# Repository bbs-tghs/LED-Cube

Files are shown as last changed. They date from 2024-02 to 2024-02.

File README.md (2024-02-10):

# LED-Cube
Eine schöne Idee, die sich als wesentlich kniffliger zeigte also zunächst vermutet.
Zunächst haben wir es mit dem ebenfalls hier beschriebenen Übungssystem versucht. Der frei fliegende Aufbau hat aber so viele Probleme verursacht, dass wir eine einzige Platine entwirfen haben, die alle erforderlichen Komponenten enthält. Das sind im Wesentlichen:
- Der Controller
- Die High-Side-Treiber
- Der Multiplexer

Diese Platine hat dann problemlos funktoniert.

So sieht das Ganze dann fertig aus. Eine Acrylglashaube schützt vor Staub. (Ein schöneres Bild brauchen wir aber noch)

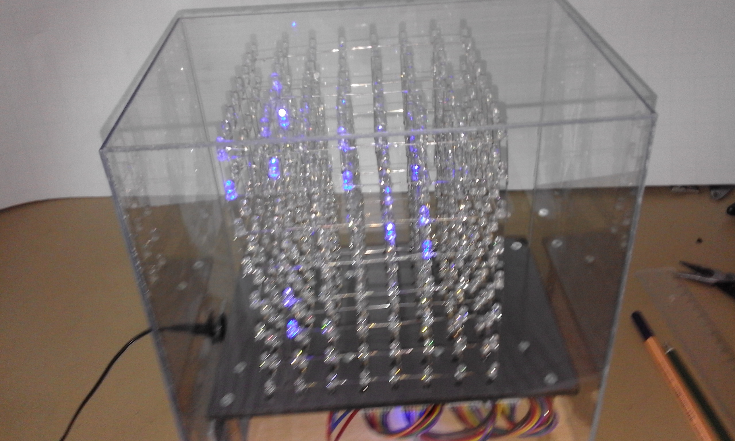
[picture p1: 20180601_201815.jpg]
LED-Cube


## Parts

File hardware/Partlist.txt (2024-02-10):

Partlist

Exported from LEDCube_Par.sch at 02.12.2017 18:35:41

EAGLE Version 5.9.0 Copyright (c) 1988-2010 CadSoft

Part     Value          Device          Package         Library          Sheet

C1       22p            C-EU050-025X075 C050-025X075    bbstghs          1
C2       22p            C-EU050-025X075 C050-025X075    bbstghs          1
C3       100n           C-EU050-025X075 C050-025X075    bbstghs          1
C4       100n           C-EU050-025X075 C050-025X075    bbstghs          1
C5       4u7            CPOL-EUE2-5     E2-5            bbstghs          1
C6       4u7            CPOL-EUE2-5     E2-5            bbstghs          1
C7       100n           C-EU050-030X075 C050-030X075    bbstghs          1
C8       100n           C-EU050-030X075 C050-030X075    bbstghs          1
C9       100n           C-EU050-030X075 C050-030X075    bbstghs          1
C10      100n           C-EU050-030X075 C050-030X075    bbstghs          1
C11      100n           C-EU050-030X075 C050-030X075    bbstghs          1
C12      100n           C-EU050-030X075 C050-030X075    bbstghs          1
C13      100n           C-EU050-030X075 C050-030X075    bbstghs          1
C14      100n           C-EU050-030X075 C050-030X075    bbstghs          1
C15      470p           C-EU050-025X075 C050-025X075    bbstghs          1
C16      470p           C-EU050-025X075 C050-025X075    bbstghs          1
C17      470p           C-EU050-025X075 C050-025X075    bbstghs          1
C18      470p           C-EU050-025X075 C050-025X075    bbstghs          1
C19      470p           C-EU050-025X075 C050-025X075    bbstghs          1
C20      470p           C-EU050-025X075 C050-025X075    bbstghs          1
C21      470p           C-EU050-025X075 C050-025X075    bbstghs          1
C22      470p           C-EU050-025X075 C050-025X075    bbstghs          1
C23      100n           C-EU050-025X075 C050-025X075    bbstghs          1
C25      47µ/25V        CPOL-EUE2-5     E2-5            bbstghs          1
C26      330n           C-EU050-030X075 C050-030X075    bbstghs          1
C27      100n           C-EU050-030X075 C050-030X075    bbstghs          1
C28      10n            C-EU050-030X075 C050-030X075    bbstghs          1
C29      100n           C-EU050-030X075 C050-030X075    bbstghs          1
C30      USB_SHIELED    USB_SHIELED     USB-MB-H-SHIELD con-usb          1
D1       SB320          SB320           DO201-15        bbstghs          1
IC1      UDN2803        ULN2803A        DIL18           uln-udn          1
IC2      UDN2803        ULN2803A        DIL18           uln-udn          1
IC3      UDN2803        ULN2803A        DIL18           uln-udn          1
IC4      UDN2803        ULN2803A        DIL18           uln-udn          1
IC5      UDN2803        ULN2803A        DIL18           uln-udn          1
IC6      UDN2803        ULN2803A        DIL18           uln-udn          1
IC7      UDN2803        ULN2803A        DIL18           uln-udn          1
IC8      UDN2803        ULN2803A        DIL18           uln-udn          1
IC9      74AC573N       74AC573N        DIL20           74xx-eu          1
IC10     74AC573N       74AC573N        DIL20           74xx-eu          1
IC11     74AC573N       74AC573N        DIL20           74xx-eu          1
IC12     74AC573N       74AC573N        DIL20           74xx-eu          1
IC13     74AC573N       74AC573N        DIL20           74xx-eu          1
IC14     74AC573N       74AC573N        DIL20           74xx-eu          1
IC15     74AC573N       74AC573N        DIL20           74xx-eu          1
IC16     74AC573N       74AC573N        DIL20           74xx-eu          1
IC17     MEGA32-P       MEGA32-P        DIL40           atmel            1
IC18                    ULN2803A        DIL18           uln-udn          1
JP1                     JP1E            JP1             bbstghs          1
JP2                     JP1E            JP1             bbstghs          1
LED1                    LED3MM          LED3MM          bbstghs          1
LED2                    LED3MM          LED3MM          bbstghs          1
LED3                    LED3MM          LED3MM          bbstghs          1
LED4                    LED3MM          LED3MM          bbstghs          1
LSP1     LSP10          LSP10           LSP10           solpad           1
LSP2     LSP10          LSP10           LSP10           solpad           1
LSP3     LSP10          LSP10           LSP10           solpad           1
LSP4     LSP11          LSP11           LSP11           solpad           1
Q1       16MHz          CRYSTALHC49U-V  HC49U-V         bbstghs          1
Q2       BD140          BD140           TO126AV         transistor-power 1
Q3       BD140          BD140           TO126AV         transistor-power 1
Q4       BD140          BD140           TO126AV         transistor-power 1
Q5       BD140          BD140           TO126AV         transistor-power 1
Q6       BD140          BD140           TO126AV         transistor-power 1
Q7       BD140          BD140           TO126AV         transistor-power 1
Q8       BD140          BD140           TO126AV         transistor-power 1
Q9       BD140          BD140           TO126AV         transistor-power 1
R1       100R           R-EU_0204/2V    0204V           bbstghs          1
R2       100R           R-EU_0204/2V    0204V           bbstghs          1
R3       100R           R-EU_0204/2V    0204V           bbstghs          1
R4       100R           R-EU_0204/2V    0204V           bbstghs          1
R5       100R           R-EU_0204/2V    0204V           bbstghs          1
R6       100R           R-EU_0204/2V    0204V           bbstghs          1
R7       100R           R-EU_0204/2V    0204V           bbstghs          1
R8       100R           R-EU_0204/2V    0204V           bbstghs          1
R9       100R           R-EU_0204/2V    0204V           bbstghs          1
R10      100R           R-EU_0204/2V    0204V           bbstghs          1
R11      100R           R-EU_0204/2V    0204V           bbstghs          1
R12      100R           R-EU_0204/2V    0204V           bbstghs          1
R13      100R           R-EU_0204/2V    0204V           bbstghs          1
R14      100R           R-EU_0204/2V    0204V           bbstghs          1
R15      100R           R-EU_0204/2V    0204V           bbstghs          1
R16      100R           R-EU_0204/2V    0204V           bbstghs          1
R17      100R           R-EU_0204/2V    0204V           bbstghs          1
R18      100R           R-EU_0204/2V    0204V           bbstghs          1
R19      100R           R-EU_0204/2V    0204V           bbstghs          1
R20      100R           R-EU_0204/2V    0204V           bbstghs          1
R21      100R           R-EU_0204/2V    0204V           bbstghs          1
R22      100R           R-EU_0204/2V    0204V           bbstghs          1
R23      100R           R-EU_0204/2V    0204V           bbstghs          1
R24      100R           R-EU_0204/2V    0204V           bbstghs          1
R25      100R           R-EU_0204/2V    0204V           bbstghs          1
R26      100R           R-EU_0204/2V    0204V           bbstghs          1
R27      100R           R-EU_0204/2V    0204V           bbstghs          1
R28      100R           R-EU_0204/2V    0204V           bbstghs          1
R29      100R           R-EU_0204/2V    0204V           bbstghs          1
R30      100R           R-EU_0204/2V    0204V           bbstghs          1
R31      100R           R-EU_0204/2V    0204V           bbstghs          1
R32      100R           R-EU_0204/2V    0204V           bbstghs          1
R33      100R           R-EU_0204/2V    0204V           bbstghs          1
R34      100R           R-EU_0204/2V    0204V           bbstghs          1
R35      100R           R-EU_0204/2V    0204V           bbstghs          1
R36      100R           R-EU_0204/2V    0204V           bbstghs          1
R37      100R           R-EU_0204/2V    0204V           bbstghs          1
R38      100R           R-EU_0204/2V    0204V           bbstghs          1
R39      100R           R-EU_0204/2V    0204V           bbstghs          1
R40      100R           R-EU_0204/2V    0204V           bbstghs          1
R41      100R           R-EU_0204/2V    0204V           bbstghs          1
R42      100R           R-EU_0204/2V    0204V           bbstghs          1
R43      100R           R-EU_0204/2V    0204V           bbstghs          1
R44      100R           R-EU_0204/2V    0204V           bbstghs          1
R45      100R           R-EU_0204/2V    0204V           bbstghs          1
R46      100R           R-EU_0204/2V    0204V           bbstghs          1
R47      100R           R-EU_0204/2V    0204V           bbstghs          1
R48      100R           R-EU_0204/2V    0204V           bbstghs          1
R49      100R           R-EU_0204/2V    0204V           bbstghs          1
R50      100R           R-EU_0204/2V    0204V           bbstghs          1
R51      100R           R-EU_0204/2V    0204V           bbstghs          1
R52      100R           R-EU_0204/2V    0204V           bbstghs          1
R53      100R           R-EU_0204/2V    0204V           bbstghs          1
R54      100R           R-EU_0204/2V    0204V           bbstghs          1
R55      100R           R-EU_0204/2V    0204V           bbstghs          1
R56      100R           R-EU_0204/2V    0204V           bbstghs          1
R57      100R           R-EU_0204/2V    0204V           bbstghs          1
R58      100R           R-EU_0204/2V    0204V           bbstghs          1
R59      100R           R-EU_0204/2V    0204V           bbstghs          1
R60      100R           R-EU_0204/2V    0204V           bbstghs          1
R61      100R           R-EU_0204/2V    0204V           bbstghs          1
R62      100R           R-EU_0204/2V    0204V           bbstghs          1
R63      100R           R-EU_0204/2V    0204V           bbstghs          1
R64      100R           R-EU_0204/2V    0204V           bbstghs          1
R65      10k            R-EU_0207/10    0207/10         bbstghs          1
R66      100k           R-EU_0207/10    0207/10         bbstghs          1
R67      10R            R-EU_0207/10    0207/10         bbstghs          1
R68      100R           R-EU_0207/2V    0207/2V         bbstghs          1
R69      100R           R-EU_0207/2V    0207/2V         bbstghs          1
R70      100R           R-EU_0207/2V    0207/2V         bbstghs          1
R71      100R           R-EU_0207/2V    0207/2V         bbstghs          1
R72      100R           R-EU_0207/2V    0207/2V         bbstghs          1
R73      100R           R-EU_0207/2V    0207/2V         bbstghs          1
R74      100R           R-EU_0207/2V    0207/2V         bbstghs          1
R75      100R           R-EU_0207/2V    0207/2V         bbstghs          1
R76      10M            R-EU_0207/10    0207/10         bbstghs          1
R77      1k8            R-EU_0207/2V    0207/2V         bbstghs          1
R78      1k8            R-EU_0207/2V    0207/2V         bbstghs          1
R79      1k8            R-EU_0207/2V    0207/2V         bbstghs          1
R80      1k8            R-EU_0207/2V    0207/2V         bbstghs          1
R81      10k            R-EU_0207/2V    0207/2V         bbstghs          1
R82      10k            R-EU_0207/2V    0207/2V         bbstghs          1
R83      4k7            R-EU_0207/10    0207/10         bbstghs          1
R84      2k2            R-EU_0207/2V    0207/2V         bbstghs          1
R86      4k7            R-EU_0207/10    0207/10         bbstghs          1
R87      2k2            R-EU_0207/2V    0207/2V         bbstghs          1
R89      4k7            R-EU_0207/10    0207/10         bbstghs          1
R90      2k2            R-EU_0207/2V    0207/2V         bbstghs          1
R92      4k7            R-EU_0207/10    0207/10         bbstghs          1
R93      2k2            R-EU_0207/2V    0207/2V         bbstghs          1
R95      4k7            R-EU_0207/10    0207/10         bbstghs          1
R96      2k2            R-EU_0207/2V    0207/2V         bbstghs          1
R98      4k7            R-EU_0207/10    0207/10         bbstghs          1
R99      2k2            R-EU_0207/2V    0207/2V         bbstghs          1
R101     4k7            R-EU_0207/10    0207/10         bbstghs          1
R102     2k2            R-EU_0207/2V    0207/2V         bbstghs          1
R104     4k7            R-EU_0207/10    0207/10         bbstghs          1
R105     2k2            R-EU_0207/2V    0207/2V         bbstghs          1
R107     10k            R-EU_0207/10    0207/10         bbstghs          1
S1                      10-XX           B3F-10XX        switch-omron     1
SV1                     MA08-1          MA08-1          con-lstb         1
SV2                     MA08-1          MA08-1          con-lstb         1
SV3                     MA08-1          MA08-1          con-lstb         1
SV4                     MA08-1          MA08-1          con-lstb         1
SV5                     MA08-1          MA08-1          con-lstb         1
SV6                     MA08-1          MA08-1          con-lstb         1
SV7                     MA08-1          MA08-1          con-lstb         1
SV8                     MA08-1          MA08-1          con-lstb         1
SV9                     MA08-1          MA08-1          con-lstb         1
SV10                    ML6             ML6             bbstghs          1
SV11                    MA08-1          MA08-1          con-lstb         1
U2       MCP2221        MCP2221         DIL14           bbstghs          1
V1       74238N         74238N          DIL16           74ttl-din        1
X1                      AK500/2         AK500/2         bbstghs          1
X2                      AK500/2         AK500/2         bbstghs          1
X3                      AK500/10        AK500/10        con-ptr500       1

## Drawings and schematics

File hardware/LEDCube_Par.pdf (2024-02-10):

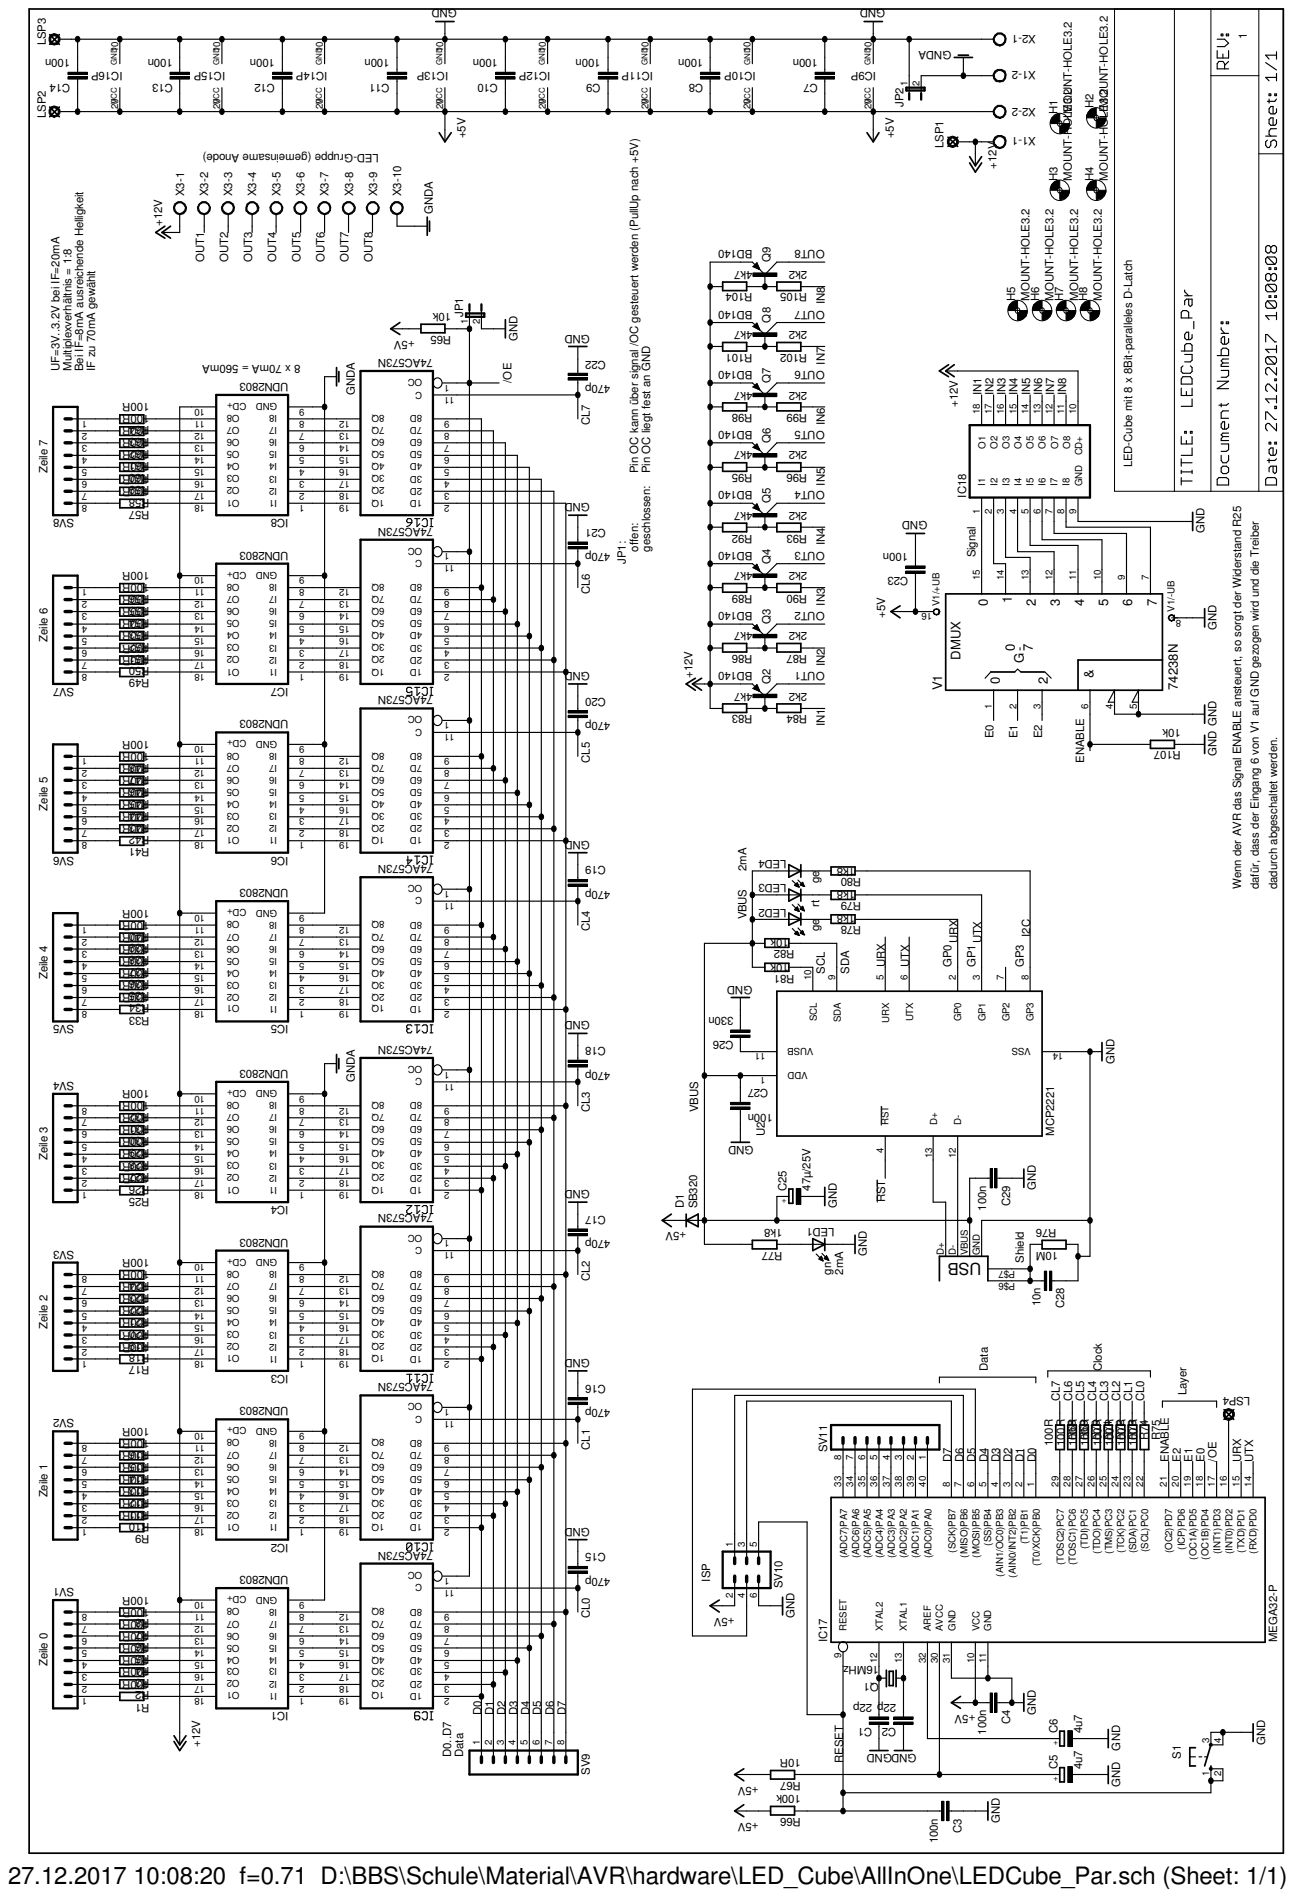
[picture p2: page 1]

Pin OC kann über signal /OC gesteuert werden (PullUp nach +5V)

Bei IF=8mA ausreichende Helligkeit

LED-Cube mit 8 x 8Bit-paralleles D-Latch

Pin OC liegt fest an GND

Zeile 7 Zeile 6 Zeile 5 Zeile 4

Wenn der AVR das Signal ENABLE ansteuert, so sorgt der Widerstand R25

dafür, dass der Eingang 6 von V1 auf GND gezogen wird und die Treiber

Zeile 3 Zeile 2 Zeile 1 Zeile 0

27.12.2017 10:08:20 f=0.71 D:\BBS\Schule\Material\AVR\hardware\LED_Cube\AllInOne\LEDCube_Par.sch (Sheet: 1/1)

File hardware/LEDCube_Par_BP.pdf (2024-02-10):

27.12.2017 10:08:53 f=1.30 D:\BBS\Schule\Material\AVR\hardware\LED_Cube\AllInOne\LEDCube_Par.brd ¹ ²

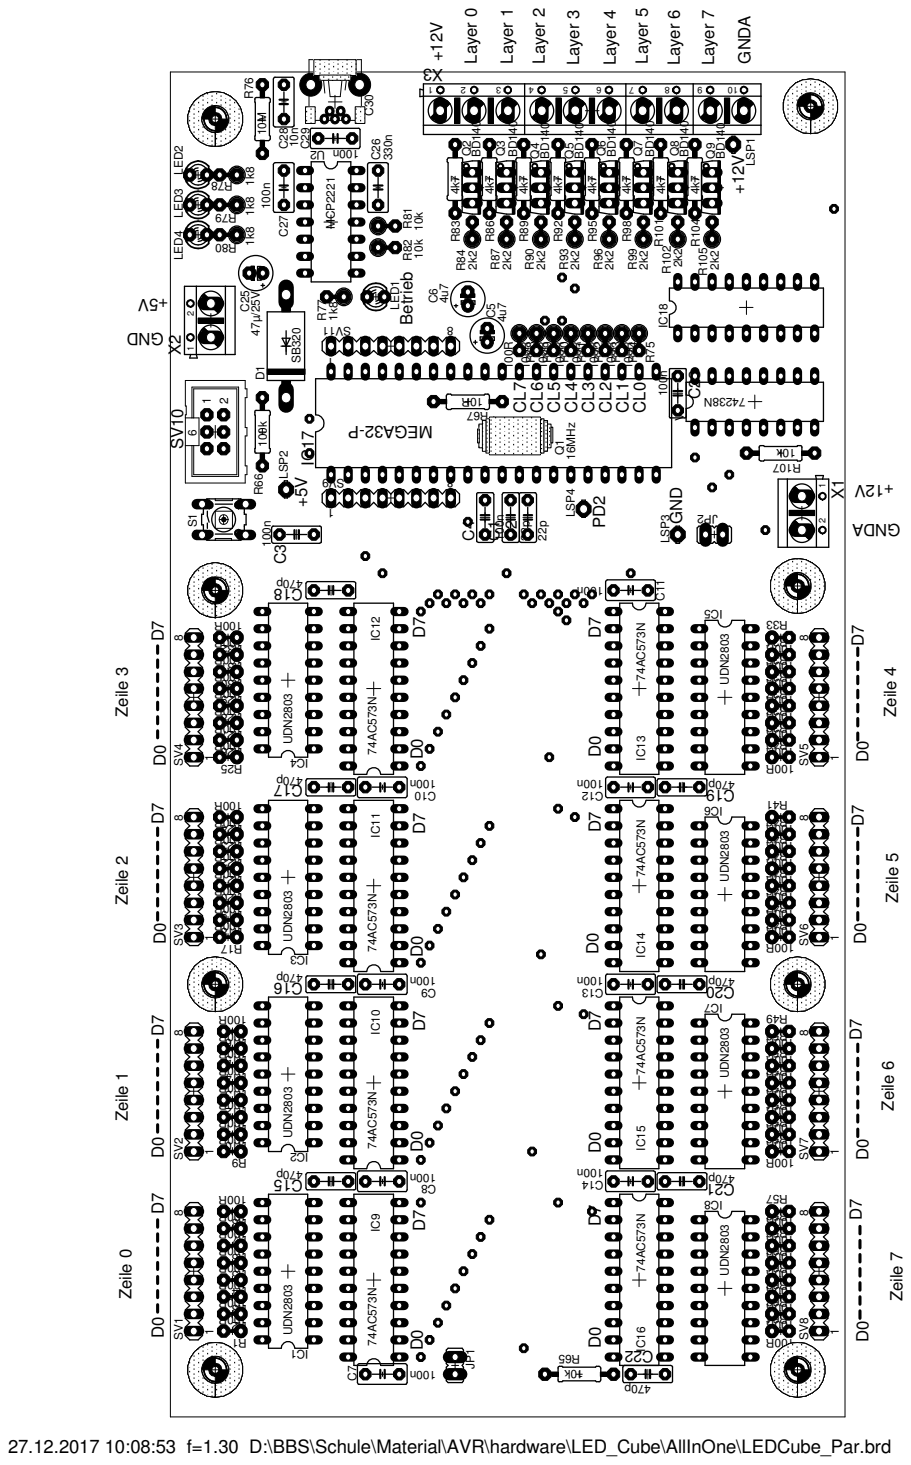
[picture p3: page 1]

Zeile 0 Zeile 1 Zeile 2 Zeile 3

Zeile 4 Zeile 5 Zeile 6 Zeile 7

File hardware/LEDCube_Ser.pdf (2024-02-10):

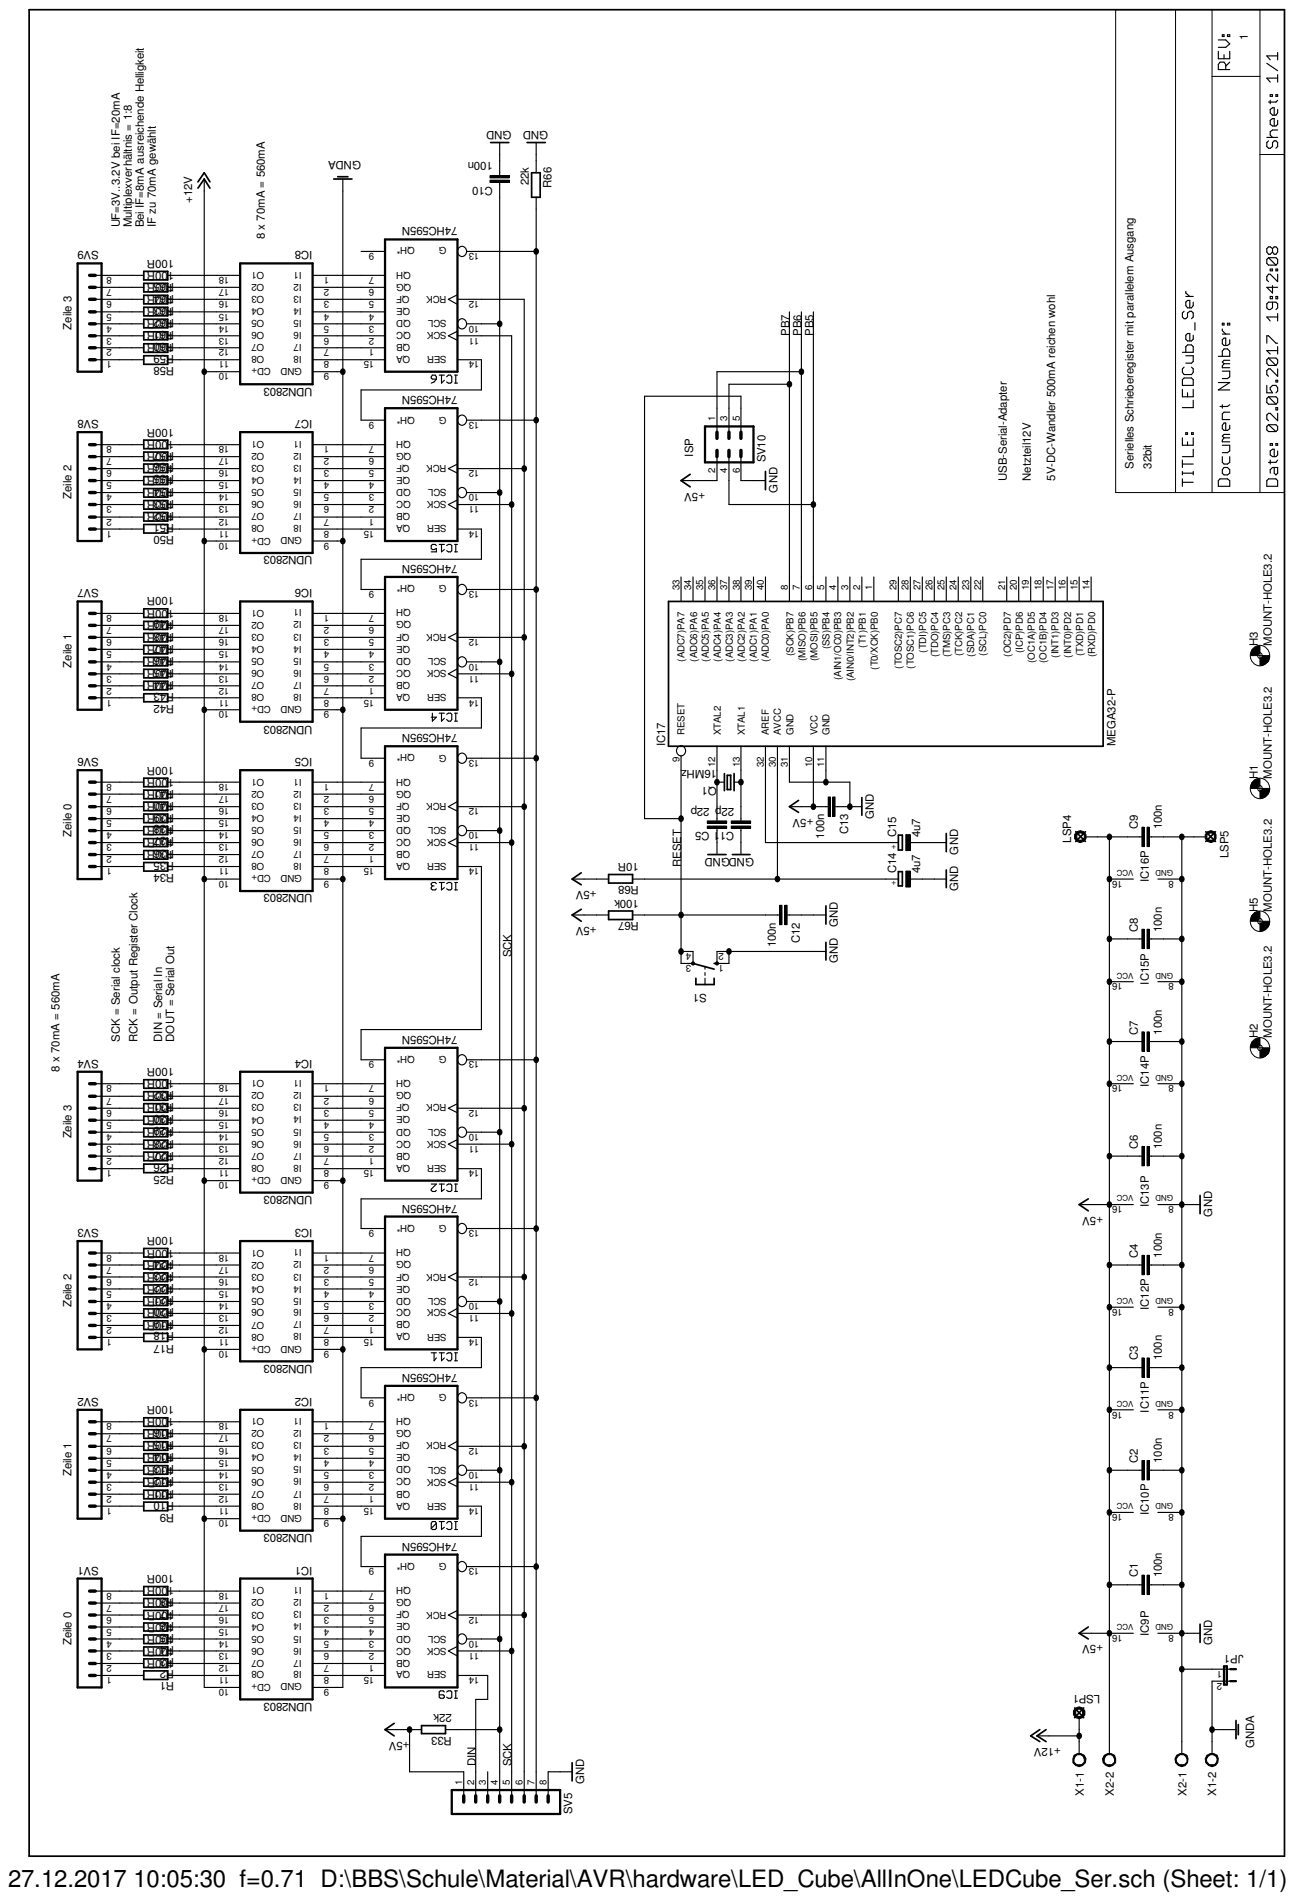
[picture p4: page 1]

Bei IF=8mA ausreichende Helligkeit

Serielles Schrieberegister mit parallelem Ausgang

Zeile 3 Zeile 2 Zeile 1 Zeile 0

5V-DC-Wandler 500mA reichen wohl

MOUNT-HOLE3.2 MOUNT-HOLE3.2

RCK = Output Register Clock

27.12.2017 10:05:30 f=0.71 D:\BBS\Schule\Material\AVR\hardware\LED_Cube\AllInOne\LEDCube_Ser.sch (Sheet: 1/1) ¹⁰⁰n

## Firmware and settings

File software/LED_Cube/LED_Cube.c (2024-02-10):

/*
 * LED_Cube.c
 *
 * Created: 08.10.2016 11:16:52
 *  Author: busser.michael
 */ 


#include <avr/io.h>
#include <avr/interrupt.h>		//Interrupts einbinden
#include <util/delay.h>
#include "timer.h"
#include "drv_573.h"
#include "uart.h"
#include "effect.h"
#include "cube.h"

#define TEST_DDR			DDRA
#define TEST_PORT			PORTA
#define TEST_SIG0			PA4
#define TEST_SIG1			PA3
#define TEST_SIG2			PA2

#define TEST_SIG_ON(n)		(TEST_PORT |=  (1<<n))
#define TEST_SIG_OFF(n)		(TEST_PORT &= ~(1<<n))
#define TEST_SIG_TOGGLE(n)	(TEST_PORT ^=  (1<<n))

#define TEST_ALL_OFF		(TEST_PORT &= ~( (1<<TEST_SIG0) | (1<<TEST_SIG1) | (1<<TEST_SIG2) ))
#define TEST_CONFIG			(TEST_DDR |=   ( (1<<TEST_SIG0) | (1<<TEST_SIG1) | (1<<TEST_SIG2) ))


// Baudrat der seriellen Schnittstelle
//#define UART_BAUD_RATE      38400
#define UART_BAUD_RATE      19200		//Mehr scheint der MCP221 nicht zu können





void cb_syncFromDriver( TCB_DRV573 cb ) {
	switch (cb) {
		case CB_SYNC		: TEST_SIG_ON(TEST_SIG0); asm volatile ("nop"); TEST_SIG_OFF(TEST_SIG0); break;	//Triggerimpuls für Scopc erzeugen, wenn Layer=0 ist
		case CB_DRIVE_ENTER : TEST_SIG_ON(TEST_SIG1);	break;	//Messen der Ausführungszeit der Funktion d573_drive
		case CB_DRIVE_LEAVE : TEST_SIG_OFF(TEST_SIG1);	break;	//gemessen:  30µs
	default:	;
	}	
}

//all functions, dealing with the commands via serial port
uint8_t cmd_getByte() {
	uint16_t c;
	c = uart_getc();
	if ((c & 0xFF00) == 0) {	//Byte received
		return( (uint8_t)c );
	} else {					//some error occured
		if ( c & UART_NO_DATA ) {		//no data available
			//not really an error...
		} else {
			//Report the errors
			if ( c & UART_FRAME_ERROR )  {		// Framing Error detected, i.e no stop bit detected
				uart_puts_P("UART Frame Error: ");
			}
			if ( c & UART_OVERRUN_ERROR ) {		// Overrun error
				uart_puts_P("UART Overrun Error: ");
			}
			if ( c & UART_BUFFER_OVERFLOW ) {	//Buffer overflow
				uart_puts_P("Buffer overflow error: ");
			}
		}
		return( 0 );	//Ok, because we do not use value 0 here
	}
}

uint8_t cmd_getNextByte(){
	uint16_t	c;
	do {									//wait for the next byte to receive
		c = uart_getc();					//blocking call
	} while ((c & 0xFF00) == UART_NO_DATA);	//returns after the next character is received
	return( (uint8_t)c );					//actually without any timeout
}


void cmd_Command() {		//Use hex-Mode in hterm for testing
	uint8_t	c;

	c = cmd_getByte();
	switch (c) {
		case 0x3F:	// ?
					uart_puts( "LED-Cube V.01\n" );		//Platzhalter...
					break;
		case 0x68:	// H - Halt
					pattern_stop();
					cube_clear();
					uart_puts( "halted\n" ); 
					break;
					
		case 0x78:	// x - Execute
					pattern_start( P_RUNNING_POINT );
					uart_puts( "started\n" );
					break;
					
		case 0x31:	
					break;			
		default: ;	//including no command
	}
}




int main(void)
{	
	
	_delay_ms(150);
	drv_init();
	drv_Register_Callback( &cb_syncFromDriver );
	
	
	timerInit();				//den Hardware-Timer initialisieren und starten
	uart_init( UART_BAUD_SELECT_DOUBLE_SPEED(UART_BAUD_RATE,F_CPU) );

	sei();
	uart_puts( "LED-Cube V.01\n" );
	
	TEST_CONFIG;
	TEST_ALL_OFF;
	
	pattern_start( P_RUNNING_POINT );		//Testweise starten		P_RUNNING_POINT
//	pattern_start( P_RAIN );				//Testweise starten		P_RUNNING_POINT
	
	
    while(1)
    {

		//Eingabe:
		cmd_Command();		//handle commands received via serial port
		
		
		if (timerFlags.flags.bMilli) {
			drv_drive();					//Multiplexing der Layer erzeugen und Daten eines Layers in die Latches schreiben
			timerClearMilli();
		}
        
		
		if (timerFlags.flags.bCenti) {
			// alle 10 ms
			pattern_do();
			timerClearCenti();
		}
	
	
		if (timerFlags.flags.bDezi) {
			// alle 100 ms
			timerClearDezi();
		}
		
		
    }
}

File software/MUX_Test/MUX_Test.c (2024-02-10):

/*
 * MUX_Test.c
 *
 * Created: 25.12.2016 09:57:58
 *  Author: busser.michael
 *
 *
 *
 *
 *
 *
 *
 *
 */ 


#include <avr/io.h>
#include <avr/interrupt.h>		//Interrupts einbinden
#include <util/delay.h>
#include "timer.h"
#include "drv_573.h"		//Test-purposes
#include "cube.h"
#include "uart.h"

/*
#define TEST_DDR			DDRB
#define TEST_PORT			PORTB
#define TEST_SIG0			PB0
#define TEST_SIG1			PB1
#define TEST_SIG2			PB2

#define TEST_SIG_ON(n)		(TEST_PORT |=  (1<<n))
#define TEST_SIG_OFF(n)		(TEST_PORT &= ~(1<<n))
#define TEST_SIG_TOGGLE(n)	(TEST_PORT ^=  (1<<n))

#define TEST_ALL_OFF		(TEST_PORT &= ~( (1<<TEST_SIG0) | (1<<TEST_SIG1) | (1<<TEST_SIG2) ))
#define TEST_CONFIG			(TEST_DDR |=   ( (1<<TEST_SIG0) | (1<<TEST_SIG1) | (1<<TEST_SIG2) ))
*/

// Baudrat der seriellen Schnittstelle
#define UART_BAUD_RATE      19200


//globale Variablen

uint8_t	test  = 0;		//0 = kein Test
						//1 = schaltet Layer layer ein- und aus

uint8_t	layer = 0;		//default: Layer 0
uint8_t latch = 0;
uint8_t	col	  = 0;
uint8_t	row	  = 0;
uint8_t	data  = 0;		//je nach Testfall

uint8_t	multiplexing = 0;	

uint8_t pattern = 0;

char asHex( uint8_t x ) {
	x = x & 0x0F;
	if ( x > 9 ) {
		return( (x-10) + 'A' );
	} else {
		return( x + '0' );
	}
}

//Rotate Right
uint8_t ror( uint8_t x ) {
	if (x & 0x01) {	//niederwertigstes Bit gesetzt
		return( (x >> 1) | 0x80 );
	} else {
		return( (x >> 1) );
	}
}

//Rotate Left
uint8_t rol( uint8_t x ) {
	if (x & 0x80) {	//höchstwertigstes Bit gesetzt
		return( (x << 1) | 0x01 );
	} else {
		return( (x << 1) );
	}
}


//all functions, dealing with the commands via serial port
uint8_t cmd_getByte() {
	uint16_t c;
	c = uart_getc();
	if ((c & 0xFF00) == 0) {	//Byte received
		return( (uint8_t)c );
	} else {					//some error occured
		if ( c & UART_NO_DATA ) {		//no data available
			//not really an error...
		} else {
			//Report the errors
			if ( c & UART_FRAME_ERROR )  {		// Framing Error detected, i.e no stop bit detected
				uart_puts_P("UART Frame Error: ");
			}
			if ( c & UART_OVERRUN_ERROR ) {		// Overrun error
				uart_puts_P("UART Overrun Error: ");
			}
			if ( c & UART_BUFFER_OVERFLOW ) {	//Buffer overflow
				uart_puts_P("Buffer overflow error: ");
			}
		}
		return( 0 );	//Ok, because we do not use value 0 here
	}
}

uint8_t cmd_getNextByte(){
	uint16_t	c;
	do {									//wait for the next byte to receive
		c = uart_getc();					//blocking call
	} while ((c & 0xFF00) == UART_NO_DATA);	//returns after the next character is received
	return( (uint8_t)c );					//actually without any timeout
}

void cmd_Command() {		//Use hex-Mode in hterm for testing
	uint8_t	c, b, a, x,y,z;

	c = cmd_getByte();
	switch (c) {
		//- Kommanods für den Test der D-FF
		case 0x63:	//'c'	Clear = Alle Latches mit 0 beschreiben
					drv_clearAllLatches();
					uart_puts( "cleared\n\0" );
					break;			
					
		case 0x64:	//'d'	set Value to D-Latch
					a = cmd_getNextByte();		//welches Latch?
					b = cmd_getNextByte();		//welcher Wert?
					latch = a % 8;
					data  = b;
					drv_test_setLatch( latch, data );
					uart_puts( "dff=" );  uart_putc( latch );  uart_puts( " set to " ); uart_putc( data ); uart_putc( '\n' );
					break;
		
		case 0x65:	a = cmd_getNextByte();
					if (a == 0) {
						D573_LATCH_OUT_DIS;  	uart_puts( "OC=1\n" );
					} else {
						D573_LATCH_OUT_EN;		uart_puts( "OC=0\n" );
					}
					break;		
		
		case 0x66 :	// High-Nibble = 0..7 (Layer)		Low Nibble = On/Off (0|1)
					a =  cmd_getNextByte();		//welcher Layer? 
					b = a & 1;					//Bitweises UND  -On/Off
					layer = (a >> 4) & 0x0F;	//Nr des Layers
					if (b > 0) {
						drv_test_setLayer( layer, _ON );
					} else {
						drv_test_setLayer( layer, _OFF );
					}
					uart_puts( "layer=\0" );  uart_putc( layer );	uart_putc( '\n' );
					break;		
		

		//- Das Array kommt ins Spiel...
		case 0x3F:	// '?'	Die akt. Testfall-Nr ausgeben
					uart_puts( "tc=\0" );  uart_putc( test );	uart_putc( '\n' );
					break;
					
		case 0x40:  // '@'
					for (int lay=0; lay<CUBE_MAX_LAYERS; lay++) {
						for (int col=0; col<CUBE_MAX_COLS; col++) {
							a = cube_getData( lay, col );	
							uart_putc( asHex(a>>4) );	uart_putc( asHex(a) ); uart_putc( ' ' );
						}
						uart_putc( '\n' );
					}
					uart_putc( '\n' );
					break;

		case 0x62:	//'c'	Clear Array
					cube_clear();
					uart_puts( "LED-Array cleared\n" );
					break;

		case 0x68:	//'h'	set Value to LED-Bitarray
					a = cmd_getNextByte();		//welches Layer  und Col
					b = cmd_getNextByte();		//welcher Wert?
					layer = (a >> 4) & 0x0F;
					col   = a & 0x0F;
					data  = b;
					cube_setData( layer, col, data );
					uart_puts( "set " ); uart_putc( layer );uart_putc( ':' );uart_putc( col );uart_putc( ':' );uart_putc( data );uart_putc( '\n' );
					break;		

		case 0x6d:	//'m'	Multiplexing ein oder ausschalten
					a = cmd_getNextByte();
					switch (a) {
						case 0:	multiplexing = 0;	break;
						case 1: multiplexing = 1;	break;
						default: ;
					}
					uart_puts( "mux=" );  uart_putc( multiplexing ); uart_putc( '\n' );
					break;

					
		case 0x74:	//'t' Select test case
					test = cmd_getNextByte();		//welcher Testfall?
					if (test == 0) { cube_clear(); }
					if (test == 0x20 ) { pattern = cmd_getNextByte(); } 	
					uart_puts( "tc=\0" );  uart_putc( test );	uart_putc( '\n' );
					break;

					
		case 0x72:	//'r'	Clear voxel
					x = cmd_getNextByte();
					y = cmd_getNextByte();
					z = cmd_getNextByte();
					cube_clearVoxel( x, y, z );	
					break;
		case 0x73:	//'s'	Set voxel
					x = cmd_getNextByte();
					y = cmd_getNextByte();
					z = cmd_getNextByte();
					cube_setVoxel( x, y, z );
					break;					
		case 0x75:	//'u'	flip voxel
					x = cmd_getNextByte();
					y = cmd_getNextByte();
					z = cmd_getNextByte();
					cube_flipVoxel( x, y, z );
					break;
					
					
		default: ;	//including no command
	}
}
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

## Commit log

2024-02-10 Dateien mit dem Suffix _Par arbeiten mit parallel ladbaren Latches. Diese Version wurde aufgebaut. Da sie einwandfrei funktionierte, haben wird die Version mit dem Suffix _Ser nicht mehr gebaut. Dabe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
    [LEDCube_Par.brd, LEDCube_Par.sch, LEDCube_Par_Conn.brd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]
2024-02-10 Einige Pläne in Eagle 5
    [Anschlussfeld.brd, Anschlussfeld.sch, Cube_LED_Matrix.sch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]
